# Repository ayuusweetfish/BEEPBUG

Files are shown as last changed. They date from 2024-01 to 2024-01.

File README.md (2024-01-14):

# BeepBug

*🚧 Final touches are work-in-progress, ETA spring 2024*

*BeepBug* is an interactive art installation, the thematic idea being that harmony between the artificial and the natural environment will supplant opposition.

The work comprises two sound-emitting cubes (or what could be perceived as shrubs), which aim to draw the audience’s attention to the delicate interconnections between naturality and artificiality. This central idea is manifested in intertextual relationships formed simultaneously in the auditory, the visual, and the cognitive domain.

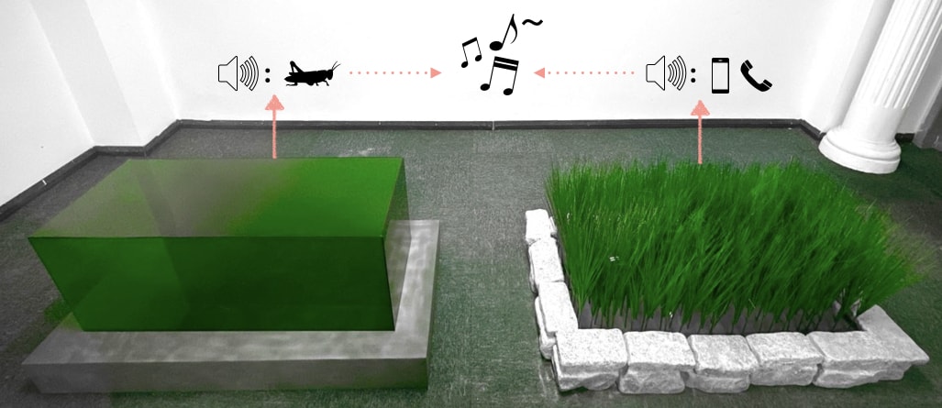
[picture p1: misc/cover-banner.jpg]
Two shrub-resembling cubes give contrasting audiovisual appearance symbolizing the artificial and the natural. The noises react to human presence and can blend into a harmonious soundscape.


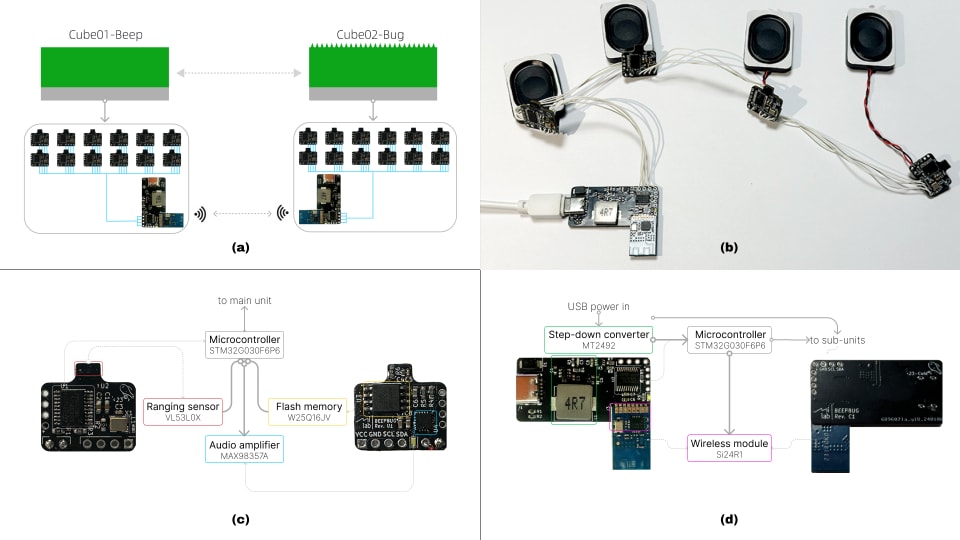
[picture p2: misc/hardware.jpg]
Explanatory figure of the composition and organization of electronic hardware.


## Current repository structure

- **flowerbed/**: The main hardware and firmware.
  - **hw/**: Hardware design for the sub units (sensor & microphone).
  - **hw_central/**: Hardware design for the main units (communication and synchronisation).
  - **fw_unit/**: Firmware for the sub units. (🚧)
- **testdrive/**: Various test & prototype implementations. Includes a crude Wizard-of-Oz implementation.

## Licence

Will switch to a proper CC licence at final release. Currently all rights reserved.

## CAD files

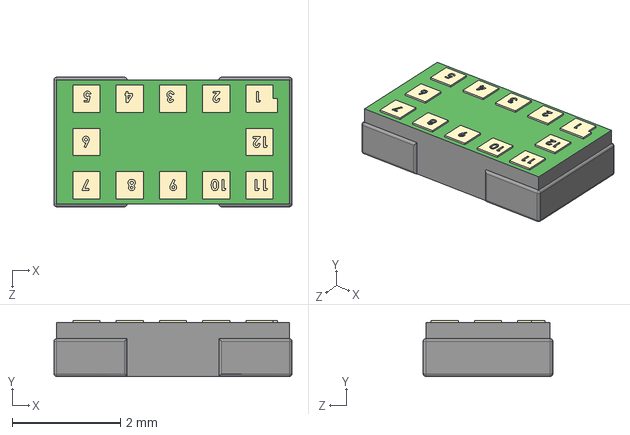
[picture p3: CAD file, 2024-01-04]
flowerbed/hw/lib_models/VL53L0X.stp
4.40 x 1.04 x 2.40 mm

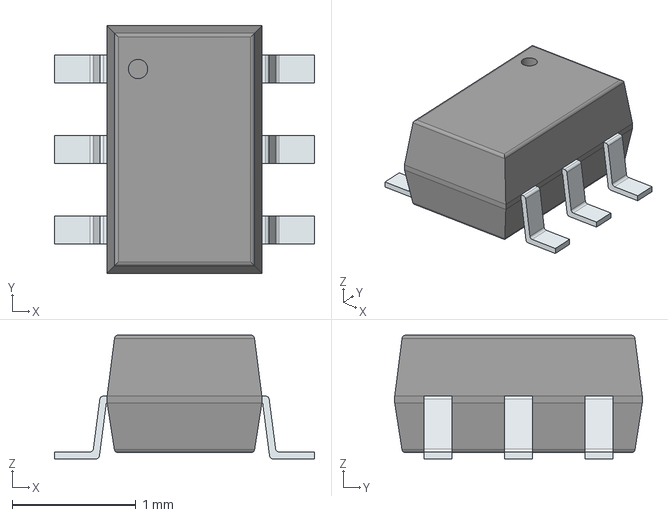
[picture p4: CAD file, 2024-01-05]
flowerbed/hw_central/lib_models/LTC4311CSC6#TRPBF.stp
2.10 x 2.00 x 1.00 mm
PinsArrayLR

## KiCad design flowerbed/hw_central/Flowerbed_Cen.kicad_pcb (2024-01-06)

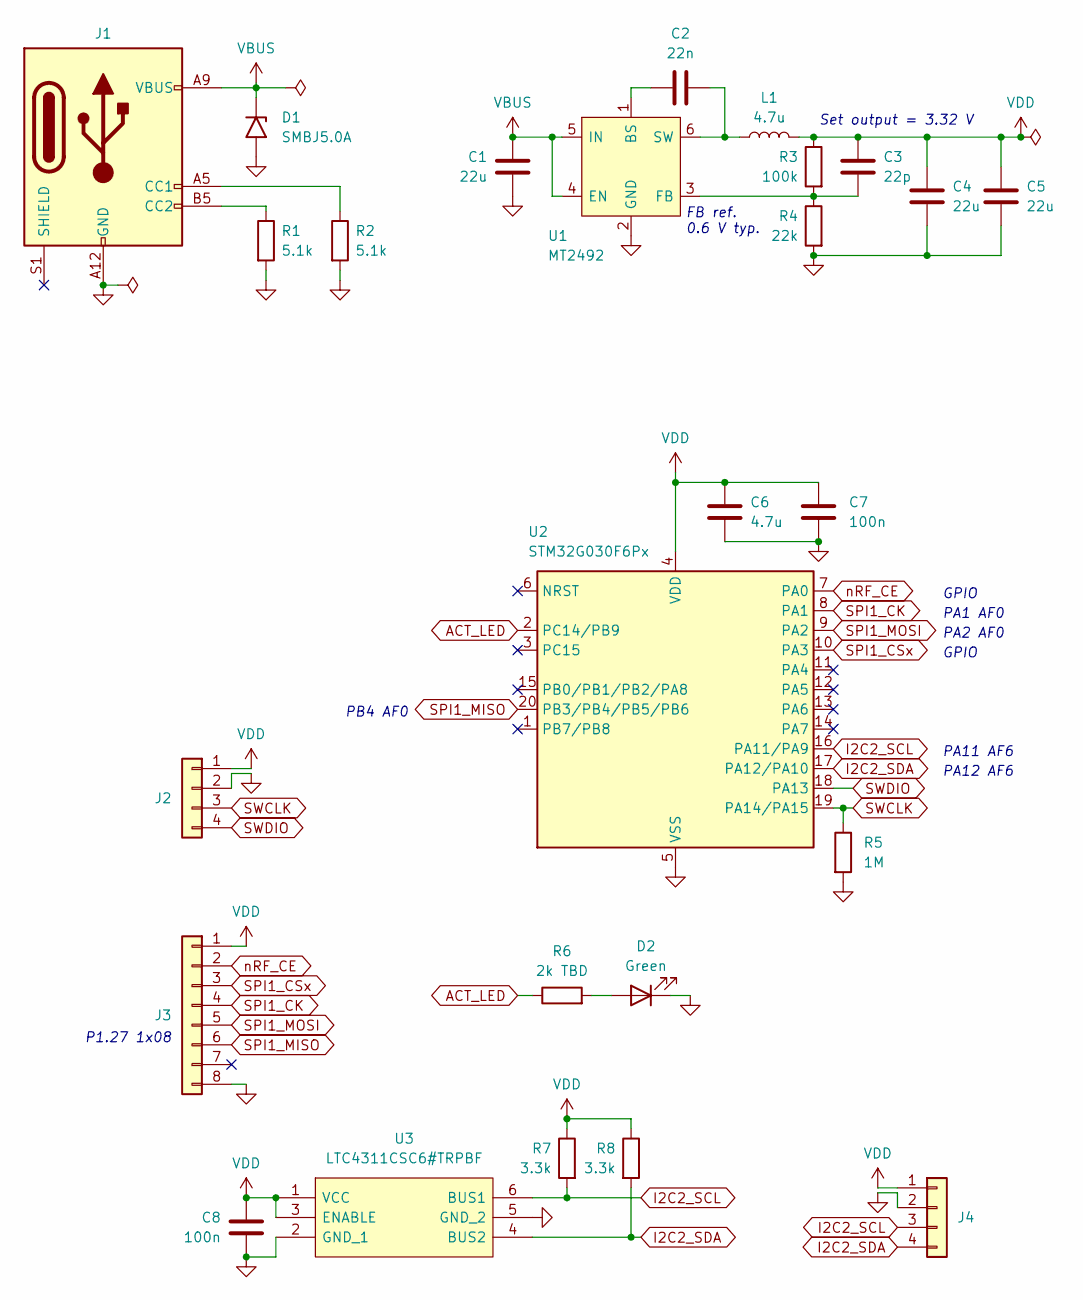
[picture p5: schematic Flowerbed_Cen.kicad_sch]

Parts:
C1, C4, C5: 22u; C_0603_1608Metric
C2: 22n; C_0603_1608Metric
C3: 22p; C_0603_1608Metric
C6: 4.7u; C_0603_1608Metric
C7, C8: 100n; C_0603_1608Metric
D1: SMBJ5.0A; D_SMB
D2: Green; LED_0603_1608Metric
J1: USB_C_Receptacle_PowerOnly_6P; USB_C_Receptacle
J2: Conn_01x04; TestPoints_1x04_P2.0
J3: Conn_01x08; SMD_Module_P1.27_1x08
J4: Conn_01x04; PinHeader_1x04_P2.54mm_Vertical
L1: 4.7u; L_Sunlord_MWSA1004S
R1, R2: 5.1k; R_0603_1608Metric
R3: 100k; R_0603_1608Metric
R4: 22k; R_0603_1608Metric
R5: 1M; R_0603_1608Metric
R6: 2k TBD; R_0603_1608Metric
R7, R8: 3.3k; R_0603_1608Metric
U1: MT2492; SOT-23-6; Manufacturer_Part_Number MT2492
U2: STM32G030F6Px; TSSOP-20_4.4x6.5mm_P0.65mm
U3: LTC4311CSC6#TRPBF; SOT65P210X100-6N; Manufacturer_Part_Number LTC4311CSC6#TRPBF; Mouser Part Number 584-LTC4311CSC6TRPBF

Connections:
ACT_LED: R6.1, U2.2 (PC14/PB9)
GND: C1.2, C4.2, C5.2, C6.2, C7.2, C8.2, D1.2 (A2), D2.1 (K), J1.A12 (GND), J1.B12 (GND), J2.2, J3.8, J4.2, R1.2, R2.2, R4.2, R5.2, U1.2 (GND), U2.5 (VSS), U3.2 (GND_1), U3.5 (GND_2)
I2C2_SCL: J4.3, R7.2, U2.16 (PA11/PA9), U3.6 (BUS1)
I2C2_SDA: J4.4, R8.2, U2.17 (PA12/PA10), U3.4 (BUS2)
unnamed: D2.2 (A), R6.2
unnamed: J1.A5 (CC1), R2.1
unnamed: J1.B5 (CC2), R1.1
unnamed: C2.1, U1.1 (BS)
unnamed: C3.2, R3.2, R4.1, U1.3 (FB)
unnamed: C2.2, L1.1, U1.6 (SW)
SPI1_CK: J3.4, U2.8 (PA1)
SPI1_CSx: J3.3, U2.10 (PA3)
SPI1_MISO: J3.6, U2.20 (PB3/PB4/PB5/PB6)
SPI1_MOSI: J3.5, U2.9 (PA2)
SWCLK: J2.3, R5.1, U2.19 (PA14/PA15)
SWDIO: J2.4, U2.18 (PA13)
VBUS: C1.1, D1.1 (A1), J1.A9 (VBUS), J1.B9 (VBUS), U1.4 (EN), U1.5 (IN)
VDD: C3.1, C4.1, C5.1, C6.1, C7.1, C8.1, J2.1, J3.1, J4.1, L1.2, R3.1, R7.1, R8.1, U2.4 (VDD), U3.1 (VCC), U3.3 (ENABLE)
nRF_CE: J3.2, U2.7 (PA0)

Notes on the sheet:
P1.27 1x08
PA1 AF0
PA11 AF6
PA2 AF0
GPIO
Set output = 3.32 V
PA12 AF6
PB4 AF0
FB ref. 0.6 V typ.

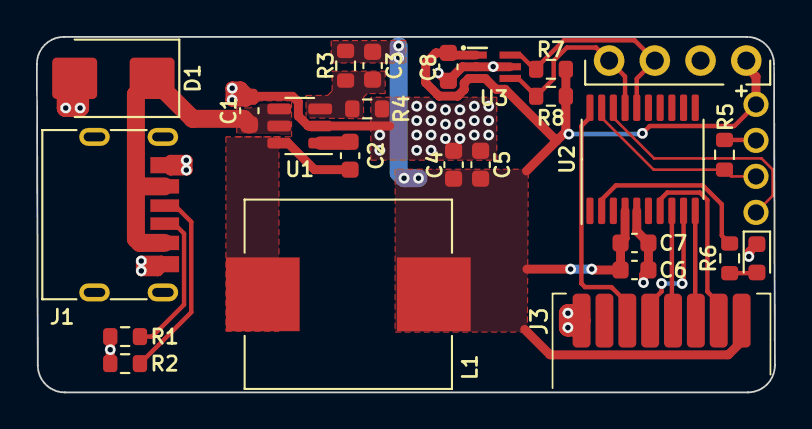
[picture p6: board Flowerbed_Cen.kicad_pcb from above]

Board: 2 copper layers, 41.0 x 19.8 mm, 26 parts (0 on the bottom side), 19 nets.

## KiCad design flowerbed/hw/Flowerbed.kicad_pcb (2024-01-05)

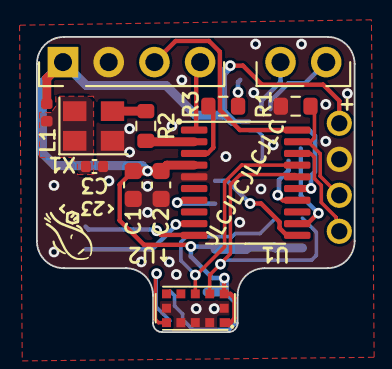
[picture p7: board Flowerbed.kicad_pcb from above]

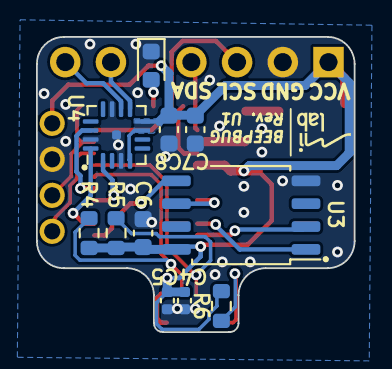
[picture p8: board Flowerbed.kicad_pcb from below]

Board: 2 copper layers, 17.7 x 16.4 mm, 24 parts (11 on the bottom side), 23 nets.

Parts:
C1: 4.7u; C_0603_1608Metric
C2, C6, C8: 100n; C_0603_1608Metric
C3, C5: 100n; C_0402_1005Metric
C4: 4.7u; C_0402_1005Metric
C7: 10u; C_0603_1608Metric
D1: Green; LED_0603_1608Metric
J1: Conn_01x04; PinHeader_1x04_P2.54mm_Vertical
J2: Conn_01x04; TestPoints_1x04_P2.0
L1: 10n; L_0402_1005Metric
LS1: Speaker; PinHeader_1x02_P2.54mm_Vertical
R1: 1M; R_0603_1608Metric
R2: 0 TBD; R_0603_1608Metric
R3: 2k TBD; R_0603_1608Metric
R4, R5: 2k; R_0603_1608Metric
R6: 10k; R_0603_1608Metric
U1: STM32G030F6Px; TSSOP-20_4.4x6.5mm_P0.65mm
U2: VL53L0X
U3: W25Q16JVSS; SOIC-8_5.23x5.23mm_P1.27mm
U4: MAX98357AETE+; QFN-16_3x3mm_P0.5mm
X1: 12.288MHz; Oscillator_SMD_Abracon_ASE-4Pin_3.2x2.5mm

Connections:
ACT_LED: R3.1, U1.3 (PC15)
GND: C1.2, C2.2, C3.2, C4.2, C5.2, C6.2, C7.2, C8.2, D1.1 (K), J1.2, J2.2, R1.2, U1.5 (VSS), U2.2 (AVSSVCSEL), U2.3 (GND), U2.4 (GND2), U2.6 (GND3), U2.12 (GND4), U3.4 (GND), U4.3 (GND_1), U4.11 (GND_2), U4.15 (GND_3), U4.17 (GND_4), X1.2 (GND)
I2C1_SCL: J1.3, U1.20 (PB3/PB4/PB5/PB6)
I2C1_SDA: J1.4, U1.1 (PB7/PB8)
I2C2_SCL: R4.2, U1.16 (PA11/PA9), U2.10 (SCL)
I2C2_SDA: R5.2, U1.17 (PA12/PA10), U2.9 (SDA)
I2S1_CK: U1.12 (PA5), U4.16 (BCLK)
I2S1_SD: U1.14 (PA7), U4.1 (DIN)
I2S1_WS: U1.15 (PB0/PB1/PB2/PA8), U4.14 (LRCLK)
unnamed: D1.2 (A), R3.2
unnamed: R2.2, U1.2 (PC14/PB9)
unnamed: R6.2, U2.5 (XSHUT)
unnamed: LS1.1, U4.10 (OUTN)
unnamed: LS1.2, U4.9 (OUTP)
unnamed: C3.1, L1.2, X1.1 (EN), X1.4 (Vdd)
unnamed: R2.1, X1.3 (OUT)
SPI2_CSx: U1.9 (PA2), U3.1 (~CS)
SPI2_MISO: U1.10 (PA3), U3.2 (DO(IO1))
SPI2_MOSI: U1.11 (PA4), U3.5 (DI(IO0))
SPI2_SCK: U1.7 (PA0), U3.6 (CLK)
SWCLK: J2.3, R1.1, U1.19 (PA14/PA15)
SWDIO: J2.4, U1.18 (PA13)
VDD: C1.1, C2.1, C4.1, C5.1, C6.1, C7.1, C8.1, J1.1, J2.1, L1.1, R4.1, R5.1, R6.1, U1.4 (VDD), U2.1 (AVDDVCSEL), U2.11 (AVDD), U3.8 (VCC), U4.4 (~SD_MODE), U4.7 (VDD_1), U4.8 (VDD_2)

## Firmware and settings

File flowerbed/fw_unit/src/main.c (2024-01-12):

#include <stm32g0xx_hal.h>
#include "vl53l0x/vl53l0x_api.h"

#define uQOA_IMPL
#include "uqoa.h"

#include <stdarg.h>
#include <stdbool.h>
#include <stdint.h>
#include <stdio.h>

#define MANUFACTURE 0
#define BEEP 1
#define BUG 0

#define ACT_LED_PORT  GPIOC
#define ACT_LED_PIN   GPIO_PIN_15

#define W25Q_CS_PORT  GPIOA
#define W25Q_CS_PIN   GPIO_PIN_2

// #define RELEASE
#ifndef RELEASE
static uint8_t swv_buf[256];
static size_t swv_buf_ptr = 0;
__attribute__ ((noinline, used))
void swv_trap_line()
{
  *(volatile char *)swv_buf;
}
static inline void swv_putchar(uint8_t c)
{
  // ITM_SendChar(c);
  if (c == '\n') {
    swv_buf[swv_buf_ptr >= sizeof swv_buf ?
      (sizeof swv_buf - 1) : swv_buf_ptr] = '\0';
    swv_trap_line();
    swv_buf_ptr = 0;
  } else if (++swv_buf_ptr <= sizeof swv_buf) {
    swv_buf[swv_buf_ptr - 1] = c;
  }
}
static void swv_printf(const char *restrict fmt, ...)
{
  char s[256];
  va_list args;
  va_start(args, fmt);
  int r = vsnprintf(s, sizeof s, fmt, args);
  for (int i = 0; i < r && i < sizeof s - 1; i++) swv_putchar(s[i]);
  if (r >= sizeof s) {
    for (int i = 0; i < 3; i++) swv_putchar('.');
    swv_putchar('\n');
  }
}
#else
#define swv_printf(...)
#endif

TIM_HandleTypeDef tim14 = { 0 };
I2C_HandleTypeDef i2c2 = { 0 };
I2S_HandleTypeDef i2s1 = { 0 };
SPI_HandleTypeDef spi2 = { 0 };

#pragma GCC optimize("O3")
static inline void spi2_transmit(uint8_t *data, size_t size)
{
  HAL_SPI_Transmit(&spi2, data, size, 1000); return;
/*
  for (int i = 0; i < size; i++) {
    while (!(SPI2->SR & SPI_SR_TXE)) { }
    SPI2->DR = data[i];
  }
  while (!(SPI2->SR & SPI_SR_TXE)) { }
  while ((SPI2->SR & SPI_SR_BSY)) { }
  // Clear OVR flag
  (void)SPI2->DR;
  (void)SPI2->SR;
*/
}

#pragma GCC optimize("O3")
static inline void spi2_receive(uint8_t *data, size_t size)
{
  HAL_SPI_Receive(&spi2, data, size, 1000); return;
/*
  for (int i = 0; i < size; i++) {
    while (!(SPI2->SR & SPI_SR_TXE)) { }
    SPI2->DR = 0;
    while (!(SPI2->SR & SPI_SR_RXNE)) { }
    data[i] = (uint8_t)SPI2->DR;
  }
  while (!(SPI2->SR & SPI_SR_TXE)) { }
  while ((SPI2->SR & SPI_SR_BSY)) { }
*/
}

#pragma GCC optimize("O3")
static inline void spi_flash_tx_rx(
  GPIO_TypeDef *cs_port, uint32_t cs_pin,
  uint8_t *txbuf, size_t txsize,
  uint8_t *rxbuf, size_t rxsize
) {
  W25Q_CS_PORT->BSRR = (uint32_t)W25Q_CS_PIN << 16;
  spi2_transmit(txbuf, txsize);
  if (rxsize != 0) {
    while (SPI1->SR & SPI_SR_BSY) { }
    spi2_receive(rxbuf, rxsize);
  }
  W25Q_CS_PORT->BSRR = (uint32_t)W25Q_CS_PIN << 0;
}

#define flash_cmd(_cmd) \
  spi_flash_tx_rx(W25Q_CS_PORT, W25Q_CS_PIN, (_cmd), sizeof (_cmd), NULL, 0)
#define flash_cmd_sized(_cmd, _cmdlen) \
  spi_flash_tx_rx(W25Q_CS_PORT, W25Q_CS_PIN, (_cmd), (_cmdlen), NULL, 0)
#define flash_cmd_bi(_cmd, _rxbuf) \
  spi_flash_tx_rx(W25Q_CS_PORT, W25Q_CS_PIN, (_cmd), sizeof (_cmd), (_rxbuf), sizeof (_rxbuf))
#define flash_cmd_bi_sized(_cmd, _cmdlen, _rxbuf, _rxlen) \
  spi_flash_tx_rx(W25Q_CS_PORT, W25Q_CS_PIN, (_cmd), (_cmdlen), (_rxbuf), (_rxlen))

uint8_t flash_status0()
{
  W25Q_CS_PORT->BSRR = (uint32_t)W25Q_CS_PIN << 16;
  uint8_t op_read_status[] = {0x05};
  spi2_transmit(op_read_status, sizeof op_read_status);
  uint8_t status0;
  spi2_receive(&status0, 1);
  W25Q_CS_PORT->BSRR = (uint32_t)W25Q_CS_PIN << 0;
  return status0;
}

__attribute__ ((noinline))
uint32_t flash_status_all()
{
  uint8_t op_read_status;
  uint8_t status[3];
  W25Q_CS_PORT->BSRR = (uint32_t)W25Q_CS_PIN << 16;
  op_read_status = 0x05; spi2_transmit(&op_read_status, 1); spi2_receive(&status[0], 1);
  W25Q_CS_PORT->BSRR = (uint32_t)W25Q_CS_PIN << 0;
  W25Q_CS_PORT->BSRR = (uint32_t)W25Q_CS_PIN << 16;
  op_read_status = 0x35; spi2_transmit(&op_read_status, 1); spi2_receive(&status[1], 1);
  W25Q_CS_PORT->BSRR = (uint32_t)W25Q_CS_PIN << 0;
  W25Q_CS_PORT->BSRR = (uint32_t)W25Q_CS_PIN << 16;
  op_read_status = 0x15; spi2_transmit(&op_read_status, 1); spi2_receive(&status[2], 1);
  W25Q_CS_PORT->BSRR = (uint32_t)W25Q_CS_PIN << 0;
  return ((uint32_t)status[2] << 16) | ((uint32_t)status[1] << 8) | status[0];
}

void flash_wait_poll(uint32_t interval_us)
{
  uint8_t status0;
  W25Q_CS_PORT->BSRR = (uint32_t)W25Q_CS_PIN << 16;
  uint8_t op_read_status[] = {0x05};
  spi2_transmit(op_read_status, sizeof op_read_status);
  do {
    // dwt_delay(interval_us * CYC_MICROSECOND);
    spi2_receive(&status0, 1);
    // swv_printf("BUSY = %u, SysTick = %lu\n", status0 & 1, HAL_GetTick());
  } while (status0 & 1);
  W25Q_CS_PORT->BSRR = (uint32_t)W25Q_CS_PIN << 0;
}

void flash_id(uint8_t jedec[3], uint8_t uid[4])
{
  uint8_t op_read_jedec[] = {0x9F};
  flash_cmd_bi_sized(op_read_jedec, sizeof op_read_jedec, jedec, 3);
  uint8_t op_read_uid[] = {0x4B, 0x00, 0x00, 0x00, 0x00};
  flash_cmd_bi_sized(op_read_uid, sizeof op_read_uid, uid, 4);
}

void flash_erase_4k(uint32_t addr)
{
  addr &= ~0xFFF;
  uint8_t op_write_enable[] = {0x06};
  flash_cmd(op_write_enable);
  uint8_t op_sector_erase[] = {
    0x20, // Sector Erase
    (addr >> 16) & 0xFF, (addr >> 8) & 0xFF, (addr >> 0) & 0xFF,
  };
  flash_cmd(op_sector_erase);
  // Wait for completion (t_SE max. = 400 ms, typ. = 40 ms)
  flash_wait_poll(1000);
}

void flash_erase_64k(uint32_t addr)
{
  addr &= ~0xFFFF;
  uint8_t op_write_enable[] = {0x06};
  flash_cmd(op_write_enable);
  uint8_t op_sector_erase[] = {
    0xD8, // 64KB Block Erase
    (addr >> 16) & 0xFF, (addr >> 8) & 0xFF, (addr >> 0) & 0xFF,
  };
  flash_cmd(op_sector_erase);
  // Wait for completion (t_BE2 max. = 2000 ms, typ. = 150 ms)
  flash_wait_poll(1000);
}

void flash_erase_chip()
{
  uint8_t op_write_enable[] = {0xC7};
  flash_cmd(op_write_enable);
  uint8_t op_chip_erase[] = {
    0x20, // Chip Erase
  };
  flash_cmd(op_chip_erase);
  // Wait for completion (t_CE max. = 25000 ms, typ. = 5000 ms)
  flash_wait_poll(10000);
}

void flash_write_page(uint32_t addr, uint8_t *data, size_t size)
{
  // assert(size > 0 && size <= 256);
  uint8_t op_write_enable[] = {0x06};
  flash_cmd(op_write_enable);
  uint8_t op_page_program[260] = {
    0x02, // Page Program
    (addr >> 16) & 0xFF, (addr >> 8) & 0xFF, (addr >> 0) & 0xFF,
  };
  for (size_t i = 0; i < size; i++)
    op_page_program[4 + i] = data[i];
  flash_cmd_sized(op_page_program, 4 + size);
  // Wait for completion (t_PP max. = 3 ms, typ. = 0.4 ms)
  flash_wait_poll(100);
}

__attribute__ ((noinline))
void flash_read(uint32_t addr, uint8_t *data, size_t size)
{
  uint8_t op_read_data[] = {
    0x03, // Read Data
    (addr >> 16) & 0xFF, (addr >> 8) & 0xFF, (addr >> 0) & 0xFF,
  };
  flash_cmd_bi_sized(op_read_data, sizeof op_read_data, data, size);
}

void flash_read_dma(uint32_t addr, uint8_t *data, size_t size)
{
  uint8_t op_read_data[] = {
    0x03, // Read Data
    (addr >> 16) & 0xFF, (addr >> 8) & 0xFF, (addr >> 0) & 0xFF,
  };
  W25Q_CS_PORT->BSRR = (uint32_t)W25Q_CS_PIN << 16;
  spi2_transmit(op_read_data, sizeof op_read_data);
  HAL_SPI_TransmitReceive_DMA(&spi2, data, data, size);
}

void flash_read_dma_wait_end()
{
  while (spi2.Instance->SR & SPI_SR_BSY) { }
  W25Q_CS_PORT->BSRR = (uint32_t)W25Q_CS_PIN << 0;
}

uint8_t flash_test_write_buf[256 * 8];

__attribute__ ((noinline))
void flash_test_write(uint32_t addr, size_t size)
{
  for (uint32_t block_start = 0; block_start < size; block_start += 256) {
    uint32_t block_size = 256;
    if (block_start + block_size >= size)
      block_size = size - block_start;
    flash_write_page(
      addr + block_start,
      flash_test_write_buf + block_start,
      block_size
    );
  }
}

void flash_test_write_breakpoint()
{
  swv_printf("all status = %06x\n", flash_status_all());
  if (*(volatile uint32_t *)flash_test_write_buf == 0x11223344) {
    uint8_t data[4] = {1, 2, 3, 4};
    flash_read(0, data, sizeof data);
    for (int i = 0; i < 4; i++) swv_printf("%d\n", data[i]);
    flash_erase_4k(0);
    flash_erase_64k(0);
    flash_erase_chip();
    flash_test_write(0, 1);
  }
  while (1) { }
}

// Audio data address range
static uint32_t audio_compressed_addr_start, audio_compressed_addr_end;
// Buffer for raw data
#define N_AUDIO_COMPR_BUF 128
static uint64_t audio_compressed_buf[N_AUDIO_COMPR_BUF];
// Next address for reading
static uint32_t audio_compressed_addr;
// Whether the decoder state should be reset
// the next time the half-buffer boundary is passed
static uint8_t audio_compressed_next_reset;
// Whether the read is in progress
static volatile bool audio_read_in_progress = 0;
// Which half of the raw data the next read should target
static uint8_t audio_compressed_half;
// Raw data consumption pointer (into the entire buffer, without knowledge of the halves)
static size_t audio_compressed_ptr;

typedef struct __attribute__ ((packed, aligned(4))) { int16_t l, r; } stereo_sample_t;
static inline stereo_sample_t sample(int16_t x) { return (stereo_sample_t){x, x}; }
// Buffer for decoded samples
#define N_AUDIO_PCM_BUF 480
static stereo_sample_t audio_pcm_buf[N_AUDIO_PCM_BUF];
// Decoder state
static qoa_lms audio_dec_state;
// Block counter, resets at 256
static uint16_t audio_block_ctr;

// Volume (12-bit fixed point, 4096 corresponds to unity gain)
static volatile uint16_t audio_volume;

// 0 - normal running
// 1 - `audio_playback_init()` would like the running thread to hold
// 2 - the running thread (through `audio_decode()` has stopped all processing)
static volatile uint8_t audio_hold_state;

static void audio_read_start();
static void audio_decode(uint8_t into_half, bool ignore_hold_state);
static void audio_playback_init(uint32_t addr_start, uint32_t addr_end)
{
  // Raise a flag for 
  audio_hold_state = 1;
  while (audio_hold_state != 2) { }

  audio_compressed_addr_start = addr_start;
  audio_compressed_addr_end = addr_end;
  audio_compressed_addr = audio_compressed_addr_start;
  audio_compressed_next_reset = 0;
  audio_compressed_half = 0;
  audio_compressed_ptr = 0;
  audio_block_ctr = 256;

  // Read the first samples and decode
  while (audio_read_in_progress) { }
  audio_read_start();
  while (audio_read_in_progress) { }
  audio_read_start();
  while (audio_read_in_progress) { }
  audio_decode(0, true);
  audio_decode(1, true);

  audio_hold_state = 0;
}

static void audio_read_start()
{
  audio_read_in_progress = true;
  if (audio_compressed_addr + (N_AUDIO_COMPR_BUF / 2) * 8 > audio_compressed_addr_end) {
    audio_compressed_addr = audio_compressed_addr_start;
    audio_compressed_next_reset = 1;
  }
  uint64_t *data = audio_compressed_buf +
    (audio_compressed_half ? N_AUDIO_COMPR_BUF / 2 : 0);
  flash_read_dma(audio_compressed_addr,
    (uint8_t *)data, N_AUDIO_COMPR_BUF / 2 * 8);
  audio_compressed_addr += (N_AUDIO_COMPR_BUF / 2) * 8;
}
static void audio_read_mark_end()
{
  uint64_t *data = audio_compressed_buf +
    (audio_compressed_half ? N_AUDIO_COMPR_BUF / 2 : 0);
  for (int i = 0; i < N_AUDIO_COMPR_BUF / 2; i++)
    data[i] = __builtin_bswap64(data[i]);
/*
  // 64-bit printing might not be supported
  swv_printf("data offset %08x -> half %d:\n",
    audio_compressed_addr - (N_AUDIO_COMPR_BUF / 2) * 8, (int)audio_compressed_half);
  for (int i = 0; i < 16; i++)
    swv_printf("%08x%08x%c",
      (uint32_t)(data[i] >> 32),
      (uint32_t)(data[i] >> 0),
      i % 4 == 3 ? '\n' : ' ');
*/
  audio_compressed_half ^= 1;
  audio_read_in_progress = false;
}
static void audio_decode(uint8_t into_half, bool ignore_hold_state)
{
  if (audio_read_in_progress) {
    swv_printf("! decode requested while data read in progress\n");
    return;
  }
  if (!ignore_hold_state && (audio_hold_state == 1 || audio_hold_state == 2)) {
    audio_hold_state = 2;
    return;
  }

  const size_t buffer_half_sz = N_AUDIO_PCM_BUF / 2;
  const size_t n_blocks = buffer_half_sz / 20;

  uint64_t *data = audio_compressed_buf + audio_compressed_ptr;
  stereo_sample_t *pcm = audio_pcm_buf + (into_half ? buffer_half_sz : 0);
  uint64_t *data_half_end =
    audio_compressed_buf + (audio_compressed_half + 1) * (N_AUDIO_COMPR_BUF / 2);
  uint16_t vol = audio_volume;
  bool start_new_read = false;
  bool decoder_reset = false; // Reset due to raw data wrap-around

  for (int i = 0; (i < n_blocks || decoder_reset); i++) {
    // `while` since `decoder_reset` might be raised inside
    while (decoder_reset || audio_block_ctr == 256) {
      decoder_reset = false;
      // Load decoder state
      for (int i = 0; i < 4; i++)
        audio_dec_state.history[i] = (int16_t)(data[0] >> (16 * (3 - i)));
      for (int i = 0; i < 4; i++)
        audio_dec_state.weights[i] = (int16_t)(data[1] >> (16 * (3 - i)));
    /*
      swv_printf("Reload (at offset %08x): %08x%08x %08x%08x\n",
        data - audio_compressed_buf,
        (uint32_t)(data[0] >> 32), (uint32_t)(data[0] >> 0),
        (uint32_t)(data[1] >> 32), (uint32_t)(data[1] >> 0));
    */
      data += 2;
      if (data == data_half_end) {
        start_new_read = true;
        if (audio_compressed_half == 1) data = audio_compressed_buf;
        if (audio_compressed_next_reset) {
          audio_compressed_next_reset = 0;
          decoder_reset = true;
        }
        /* swv_printf("Past half (%d): first value is %08x%08x\n",
          audio_compressed_half,
          (uint32_t)(data[0] >> 32), (uint32_t)(data[0] >> 0)); */
      }
      audio_block_ctr = 0;
    }
    if (i >= n_blocks) break;
    int16_t decoded_pcm[20];
    qoa_decode_slice(&audio_dec_state, *data, decoded_pcm);
    for (int i = 0; i < 20; i++)
      pcm[i] = sample(((int32_t)decoded_pcm[i] * vol) >> 12);
    /* if (n_called == 6 || start_new_read) {
      swv_printf("data: %08x%08x\ndecoded: ",
        (uint32_t)(data[0] >> 32), (uint32_t)(data[0] >> 0));
      for (int i = 0; i < 20; i++)
        swv_printf("%04x%c", (uint32_t)(uint16_t)pcm[i], i == 19 ? '\n' : ' ');
    } */
    data += 1;
    if (data == data_half_end) {
      start_new_read = true;
      if (audio_compressed_half == 1) data = audio_compressed_buf;
      if (audio_compressed_next_reset) {
        audio_compressed_next_reset = 0;
        decoder_reset = true;
        /* swv_printf("Past half (%d): next reset, first value is %08x%08x\n",
          audio_compressed_half,
          (uint32_t)(data[0] >> 32), (uint32_t)(data[0] >> 0)); */
      }
    }
    pcm += 20;
    audio_block_ctr += 1;
  }

  // Move data consumption pointer
  audio_compressed_ptr = data - audio_compressed_buf;
  if (start_new_read) {
    // swv_printf("raw data refill initiated\n");
    audio_read_start();
  }
}

int main()
{
  HAL_Init();

  // ======== GPIO ========
  __HAL_RCC_GPIOA_CLK_ENABLE();
  __HAL_RCC_GPIOB_CLK_ENABLE();
  __HAL_RCC_GPIOC_CLK_ENABLE();
  GPIO_InitTypeDef gpio_init;

  // Act LED
  gpio_init = (GPIO_InitTypeDef){
    .Pin = ACT_LED_PIN,
    .Mode = GPIO_MODE_OUTPUT_PP,
    .Pull = GPIO_NOPULL,
    .Speed = GPIO_SPEED_FREQ_HIGH,
  };
  HAL_GPIO_Init(ACT_LED_PORT, &gpio_init);
  HAL_GPIO_WritePin(ACT_LED_PORT, ACT_LED_PIN, 0);

  // SWD (PA13, PA14)
  gpio_init.Pin = GPIO_PIN_13 | GPIO_PIN_14;
  gpio_init.Mode = GPIO_MODE_AF_PP; // Pass over control to AF peripheral
  gpio_init.Alternate = GPIO_AF0_SWJ;
  gpio_init.Pull = GPIO_PULLUP;
  gpio_init.Speed = GPIO_SPEED_FREQ_HIGH;
  HAL_GPIO_Init(GPIOA, &gpio_init);

  // ======== Clocks ========
  RCC_OscInitTypeDef osc_init = { 0 };
  osc_init.OscillatorType = RCC_OSCILLATORTYPE_HSE;
  osc_init.HSEState = RCC_HSE_BYPASS;
  osc_init.PLL.PLLState = RCC_PLL_ON;
  osc_init.PLL.PLLSource = RCC_PLLSOURCE_HSE;
  osc_init.PLL.PLLM = RCC_PLLM_DIV1;  // VCO input 12.288 MHz (2.66 ~ 16 MHz)
  osc_init.PLL.PLLN = 12;             // VCO output 147.456 MHz (64 ~ 344 MHz)
  osc_init.PLL.PLLP = RCC_PLLP_DIV4;  // PLLPCLK 36.864 MHz
  osc_init.PLL.PLLR = RCC_PLLR_DIV4;  // PLLRCLK 36.864 MHz
  HAL_RCC_OscConfig(&osc_init);

  RCC_ClkInitTypeDef clk_init = { 0 };
  clk_init.ClockType =
    RCC_CLOCKTYPE_SYSCLK |
    RCC_CLOCKTYPE_HCLK |
    RCC_CLOCKTYPE_PCLK1;
  clk_init.SYSCLKSource = RCC_SYSCLKSOURCE_PLLCLK;  // PLLRCLK
  clk_init.AHBCLKDivider = RCC_SYSCLK_DIV1;
  clk_init.APB1CLKDivider = RCC_HCLK_DIV1;
  HAL_RCC_ClockConfig(&clk_init, FLASH_LATENCY_2);

  HAL_NVIC_SetPriority(SysTick_IRQn, 0, 0);

  for (int i = 0; i < 2; i++) {
    HAL_GPIO_WritePin(ACT_LED_PORT, ACT_LED_PIN, 1); HAL_Delay(100);
    HAL_GPIO_WritePin(ACT_LED_PORT, ACT_LED_PIN, 0); HAL_Delay(100);
  }

  // ======== Timer ========
  __HAL_RCC_TIM14_CLK_ENABLE();
  tim14 = (TIM_HandleTypeDef){
    .Instance = TIM14,
    .Init = {
      // 36.864 MHz
      .Prescaler = 2304 - 1,
      .CounterMode = TIM_COUNTERMODE_UP,
      .Period = 16000 - 1,
      .ClockDivision = TIM_CLOCKDIVISION_DIV1,
      .RepetitionCounter = 0,
    },
  };
  HAL_TIM_Base_Init(&tim14);
  HAL_TIM_Base_Start_IT(&tim14);
  __HAL_TIM_ENABLE_IT(&tim14, TIM_IT_UPDATE);
  HAL_NVIC_SetPriority(TIM14_IRQn, 1, 0);
  HAL_NVIC_EnableIRQ(TIM14_IRQn);

  // ======== I2C ========
  gpio_init.Pin = GPIO_PIN_11 | GPIO_PIN_12;
  gpio_init.Mode = GPIO_MODE_AF_PP;
  gpio_init.Alternate = GPIO_AF6_I2C2;
  gpio_init.Pull = GPIO_NOPULL;
  gpio_init.Speed = GPIO_SPEED_FREQ_HIGH;
  HAL_GPIO_Init(GPIOA, &gpio_init);

  __HAL_RCC_I2C2_CLK_ENABLE();
  i2c2 = (I2C_HandleTypeDef){
    .Instance = I2C2,
    .Init = {
      // RM0454 Rev 5, pp. 711, 726, 738 (examples), 766 (reg. map)
      // APB = 36.864 MHz
      // f_SCL = 368.64 kHz = APB / 100
      // PRESC = 9 (scaled clock APB / 10 = 0.2713 µs)
      // SCLDEL = 0x1, SDADEL = 0x1,
      // SCLH = 0x03 (0.8138 µs > 0.6 µs), SCLL = 0x05 (1.356 µs > 1.3 µs)
      .Timing = 0x90110305,
      .OwnAddress1 = 0x00,
      .AddressingMode = I2C_ADDRESSINGMODE_7BIT,
    },
  };
  HAL_I2C_Init(&i2c2);

  // ======== DMA for I2S ========
  __HAL_RCC_DMA1_CLK_ENABLE();
  // RM0454, Ch. 9.3.2 —
  // DMA channels are multiplexed instead of hard-wired like the 'F103C6
  DMA_HandleTypeDef dma_i2s1_tx;
  dma_i2s1_tx.Instance = DMA1_Channel1;
  dma_i2s1_tx.Init.Request = DMA_REQUEST_SPI1_TX;
  dma_i2s1_tx.Init.Direction = DMA_MEMORY_TO_PERIPH;
  dma_i2s1_tx.Init.PeriphInc = DMA_PINC_DISABLE;
  dma_i2s1_tx.Init.MemInc = DMA_MINC_ENABLE;
  dma_i2s1_tx.Init.PeriphDataAlignment = DMA_PDATAALIGN_HALFWORD;
  dma_i2s1_tx.Init.MemDataAlignment = DMA_MDATAALIGN_HALFWORD;
  dma_i2s1_tx.Init.Mode = DMA_CIRCULAR;
  dma_i2s1_tx.Init.Priority = DMA_PRIORITY_LOW;
  HAL_DMA_Init(&dma_i2s1_tx);

  HAL_NVIC_SetPriority(DMA1_Channel1_IRQn, 15, 1);
  HAL_NVIC_EnableIRQ(DMA1_Channel1_IRQn);
  HAL_NVIC_SetPriority(SPI1_IRQn, 15, 2);
  HAL_NVIC_EnableIRQ(SPI1_IRQn);

  // ======== I2S ========
  gpio_init.Pin = GPIO_PIN_5 | GPIO_PIN_7;
  gpio_init.Mode = GPIO_MODE_AF_PP;
  gpio_init.Alternate = GPIO_AF0_SPI1;
  gpio_init.Pull = GPIO_PULLUP;
  gpio_init.Speed = GPIO_SPEED_FREQ_HIGH;
  HAL_GPIO_Init(GPIOA, &gpio_init);

  gpio_init.Pin = GPIO_PIN_0;
  HAL_GPIO_Init(GPIOB, &gpio_init);

  __HAL_RCC_SPI1_CLK_ENABLE();
  i2s1 = (I2S_HandleTypeDef){
    .Instance = SPI1,
    .Init = {
      .Mode = I2S_MODE_MASTER_TX,
      .Standard = I2S_STANDARD_PHILIPS,
      .DataFormat = I2S_DATAFORMAT_16B,
      .MCLKOutput = I2S_MCLKOUTPUT_DISABLE,
      .AudioFreq = I2S_AUDIOFREQ_48K,
      .CPOL = I2S_CPOL_LOW,
    },
  };
  __HAL_LINKDMA(&i2s1, hdmatx, dma_i2s1_tx);
  HAL_I2S_Init(&i2s1);

  swv_printf("sys clock = %u\n", HAL_RCC_GetSysClockFreq());
  swv_printf("I2S clock = %u\n", HAL_RCCEx_GetPeriphCLKFreq(RCC_PERIPHCLK_I2S1));
  // 36864000, divider is 36864000 / 16 / 48k = 48

  // ======== DMA for SPI ========
  DMA_HandleTypeDef dma_spi2_tx;
  dma_spi2_tx.Instance = DMA1_Channel2;
  dma_spi2_tx.Init.Request = DMA_REQUEST_SPI2_TX;
  dma_spi2_tx.Init.Direction = DMA_MEMORY_TO_PERIPH;
  dma_spi2_tx.Init.PeriphInc = DMA_PINC_DISABLE;
  dma_spi2_tx.Init.MemInc = DMA_MINC_ENABLE;
  dma_spi2_tx.Init.PeriphDataAlignment = DMA_PDATAALIGN_BYTE;
  dma_spi2_tx.Init.MemDataAlignment = DMA_MDATAALIGN_BYTE;
  dma_spi2_tx.Init.Mode = DMA_NORMAL;
  dma_spi2_tx.Init.Priority = DMA_PRIORITY_LOW;
  HAL_DMA_Init(&dma_spi2_tx);

  DMA_HandleTypeDef dma_spi2_rx;
  dma_spi2_rx.Instance = DMA1_Channel3;
  dma_spi2_rx.Init.Request = DMA_REQUEST_SPI2_RX;
  dma_spi2_rx.Init.Direction = DMA_PERIPH_TO_MEMORY;
  dma_spi2_rx.Init.PeriphInc = DMA_PINC_DISABLE;
  dma_spi2_rx.Init.MemInc = DMA_MINC_ENABLE;
  dma_spi2_rx.Init.PeriphDataAlignment = DMA_PDATAALIGN_BYTE;
  dma_spi2_rx.Init.MemDataAlignment = DMA_MDATAALIGN_BYTE;
  dma_spi2_rx.Init.Mode = DMA_NORMAL;
  dma_spi2_rx.Init.Priority = DMA_PRIORITY_LOW;
  HAL_DMA_Init(&dma_spi2_rx);

  HAL_NVIC_SetPriority(DMA1_Channel2_3_IRQn, 15, 3);
  HAL_NVIC_EnableIRQ(DMA1_Channel2_3_IRQn);
  HAL_NVIC_SetPriority(SPI2_IRQn, 15, 4);
  HAL_NVIC_EnableIRQ(SPI2_IRQn);

  // ======== SPI ========
  gpio_init.Pin = GPIO_PIN_0 | GPIO_PIN_3;
  gpio_init.Mode = GPIO_MODE_AF_PP;
  gpio_init.Pull = GPIO_PULLUP;
  gpio_init.Speed = GPIO_SPEED_FREQ_HIGH;
  gpio_init.Alternate = GPIO_AF0_SPI2;
  HAL_GPIO_Init(GPIOA, &gpio_init);

  gpio_init.Pin = GPIO_PIN_4;
  gpio_init.Alternate = GPIO_AF1_SPI2;
  HAL_GPIO_Init(GPIOA, &gpio_init);

  gpio_init.Pin = W25Q_CS_PIN;
  gpio_init.Mode = GPIO_MODE_OUTPUT_PP;
  HAL_GPIO_Init(W25Q_CS_PORT, &gpio_init);
  HAL_GPIO_WritePin(W25Q_CS_PORT, W25Q_CS_PIN, 1);

  __HAL_RCC_SPI2_CLK_ENABLE();
  spi2.Instance = SPI2;
  spi2.Init.Mode = SPI_MODE_MASTER;
  spi2.Init.Direction = SPI_DIRECTION_2LINES;
  spi2.Init.CLKPolarity = SPI_POLARITY_LOW; // CPOL = 0
  spi2.Init.CLKPhase = SPI_PHASE_1EDGE;     // CPHA = 0
  spi2.Init.NSS = SPI_NSS_SOFT;
  spi2.Init.FirstBit = SPI_FIRSTBIT_MSB;
  spi2.Init.TIMode = SPI_TIMODE_DISABLE;
  spi2.Init.CRCCalculation = SPI_CRCCALCULATION_DISABLE;
  spi2.Init.DataSize = SPI_DATASIZE_8BIT;
  spi2.Init.BaudRatePrescaler = SPI_BAUDRATEPRESCALER_2;  // APB / 2 = 18.432 MHz
  __HAL_LINKDMA(&spi2, hdmatx, dma_spi2_tx);
  __HAL_LINKDMA(&spi2, hdmarx, dma_spi2_rx);
  HAL_SPI_Init(&spi2);
  __HAL_SPI_ENABLE(&spi2);
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

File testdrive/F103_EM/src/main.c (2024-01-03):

#include <stm32f1xx_hal.h>
#include <stdarg.h>
#include <stdbool.h>
#include <stdint.h>
#include <stdio.h>

static uint8_t swv_buf[256];
static size_t swv_buf_ptr = 0;
__attribute__ ((noinline, used))
void swv_trap_line()
{
  *(volatile char *)swv_buf;
}
static inline void swv_putchar(uint8_t c)
{
  // ITM_SendChar(c);
  if (c == '\n') {
    swv_buf[swv_buf_ptr >= sizeof swv_buf ?
      (sizeof swv_buf - 1) : swv_buf_ptr] = '\0';
    swv_trap_line();
    swv_buf_ptr = 0;
  } else if (++swv_buf_ptr <= sizeof swv_buf) {
    swv_buf[swv_buf_ptr - 1] = c;
  }
}
static void swv_printf(const char *restrict fmt, ...)
{
  char s[256];
  va_list args;
  va_start(args, fmt);
  int r = vsnprintf(s, sizeof s, fmt, args);
  for (int i = 0; i < r && i < sizeof s - 1; i++) swv_putchar(s[i]);
  if (r >= sizeof s) {
    for (int i = 0; i < 3; i++) swv_putchar('.');
    swv_putchar('\n');
  }
}

TIM_HandleTypeDef tim2 = { 0 };

int main()
{
  HAL_Init();

  // ======== GPIO ========
  __HAL_RCC_GPIOA_CLK_ENABLE();
  __HAL_RCC_GPIOB_CLK_ENABLE();
  __HAL_RCC_GPIOC_CLK_ENABLE();
  GPIO_InitTypeDef gpio_init;

/*
  gpio_init.Pin = GPIO_PIN_1;
  gpio_init.Mode = GPIO_MODE_OUTPUT_PP;
  gpio_init.Pull = GPIO_PULLUP;
  gpio_init.Speed = GPIO_SPEED_FREQ_HIGH;
  HAL_GPIO_Init(GPIOA, &gpio_init);
  HAL_GPIO_WritePin(GPIOA, GPIO_PIN_1, GPIO_PIN_RESET);
*/

  // ======== Clocks ========
  RCC_OscInitTypeDef osc_init = { 0 };
  osc_init.OscillatorType = RCC_OSCILLATORTYPE_HSE;
  osc_init.HSEState = RCC_HSE_ON;
  osc_init.PLL.PLLState = RCC_PLL_ON;
  osc_init.PLL.PLLSource = RCC_PLLSOURCE_HSE;
  osc_init.PLL.PLLMUL = RCC_PLL_MUL9;
  HAL_RCC_OscConfig(&osc_init);

  RCC_ClkInitTypeDef clk_init = { 0 };
  clk_init.ClockType =
    RCC_CLOCKTYPE_SYSCLK |
    RCC_CLOCKTYPE_HCLK |
    RCC_CLOCKTYPE_PCLK1 |
    RCC_CLOCKTYPE_PCLK2;
  clk_init.SYSCLKSource = RCC_SYSCLKSOURCE_PLLCLK;
  clk_init.AHBCLKDivider = RCC_SYSCLK_DIV1;
  clk_init.APB1CLKDivider = RCC_HCLK_DIV2;
  clk_init.APB2CLKDivider = RCC_HCLK_DIV1;
  HAL_RCC_ClockConfig(&clk_init, FLASH_LATENCY_2);

  // Cycle count
  CoreDebug->DEMCR &= ~CoreDebug_DEMCR_TRCENA_Msk;
  CoreDebug->DEMCR |=  CoreDebug_DEMCR_TRCENA_Msk;
  DWT->CTRL &= ~DWT_CTRL_CYCCNTENA_Msk;
  DWT->CTRL |=  DWT_CTRL_CYCCNTENA_Msk;
  DWT->CYCCNT = 0;

  HAL_NVIC_SetPriority(SysTick_IRQn, 0, 0);

  // ======== Timer ========
  // TIM2_CH2 (PA1)
  gpio_init.Pin = GPIO_PIN_1;
  gpio_init.Mode = GPIO_MODE_AF_PP;
  gpio_init.Pull = GPIO_NOPULL;
  gpio_init.Speed = GPIO_SPEED_FREQ_HIGH;
  HAL_GPIO_Init(GPIOA, &gpio_init);

  // 72 MHz clock, 7.2 kHz PWM, resolution ~10 bits (max. 1000)
  tim2 = (TIM_HandleTypeDef){
    .Instance = TIM2,
    .Init = {
      .Prescaler = 1 - 1,
      .CounterMode = TIM_COUNTERMODE_UP,
      .Period = 10000 - 1,
      .ClockDivision = TIM_CLOCKDIVISION_DIV1,
      .RepetitionCounter = 0,
    },
  };
  TIM_OC_InitTypeDef tim2_ch2_oc_init = {
    .OCMode = TIM_OCMODE_PWM1,
    .Pulse = 100, // to be filled
    .OCPolarity = TIM_OCPOLARITY_HIGH,
  };
  __HAL_RCC_TIM2_CLK_ENABLE();
  HAL_TIM_PWM_Init(&tim2);
  HAL_TIM_PWM_ConfigChannel(&tim2, &tim2_ch2_oc_init, TIM_CHANNEL_2);
  HAL_TIM_PWM_Start(&tim2, TIM_CHANNEL_2);
  while (1) {
    for (int i = 90; i < 100; i++) {
      TIM2->CCR2 = i * 100;
      HAL_Delay(150);
    }
  }

/*
  while (1) {
    HAL_GPIO_WritePin(GPIOA, GPIO_PIN_1, GPIO_PIN_SET);
    HAL_Delay(1);
    HAL_GPIO_WritePin(GPIOA, GPIO_PIN_1, GPIO_PIN_RESET);
    HAL_Delay(99);
  }
*/
  while (1) { }
}

void SysTick_Handler()
{
  HAL_IncTick();
  HAL_SYSTICK_IRQHandler();
}

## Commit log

2024-01-01 (WIP) Wizard of Oz framework
2024-01-01 Finish Wizard of Oz prototype
2024-01-02 Switch Oz from distributed Deno Deploy to WLAN server
2024-01-03 Adjust PWM duty cycle; confirm electromagnet characteristics
    The electromagnet is bistable; i.e. is not easily released once in the activated position. It is thus unsuitable for precision position control.
2024-01-04 Create circuit board for flowerbed units
    [Flowerbed.kicad_pcb, Flowerbed.kicad_sch, VL53L0X.stp]
2024-01-04 Flowerbed unit layout?
    [Flowerbed.kicad_pcb, Flowerbed.kicad_sch]
2024-01-04 Revise flowerbed unit layout
    [Flowerbed.kicad_pcb]
2024-01-04 (WIP) Add flowerbed central schematic
    [Flowerbed.kicad_pcb, Flowerbed.kicad_sch, Flowerbed_Cen.kicad_pcb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]
2024-01-05 Route flowerbed unit (!)
    [Flowerbed.kicad_pcb, Flowerbed.kicad_sch]
2024-01-05 Finalize flowerbed unit PCB design
    [Flowerbed.kicad_pcb]
2024-01-05 Finish flowerbed central schematic
    [Flowerbed_Cen.kicad_sch, LTC4311CSC6#TRPBF.stp]
2024-01-06 Finish flowerbed central board; submit for fab
    [Flowerbed_Cen.kicad_pcb, Flowerbed_Cen.kicad_sch]
2024-01-11 Blinking LED on unit hardware
2024-01-11 Verify VL53L0X I2C communication
2024-01-11 I2S through DMA circular/double buffer
2024-01-11 Read flash with DMA
2024-01-11 Use combined IRQ lines for SPI DMA TX/RX
2024-01-12 Correctly decode audio samples
    [main.c, uqoa.h]
2024-01-12 Signal mechanism in playback to prevent fleeting glitches
    [main.c]
2024-01-12 Fade audio according to ToF sensor read-outs
